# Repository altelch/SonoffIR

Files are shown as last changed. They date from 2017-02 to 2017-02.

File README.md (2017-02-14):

# SonoffIR
Sonoff IR remote controll extension for [Sonoff-Tasmota](https://github.com/arendst/Sonoff-Tasmota "Sonoff-Tasmota") and [iTead Sonoff Basic](http://sonoff.itead.cc/en/products/sonoff/sonoff-basic).
## Schematics
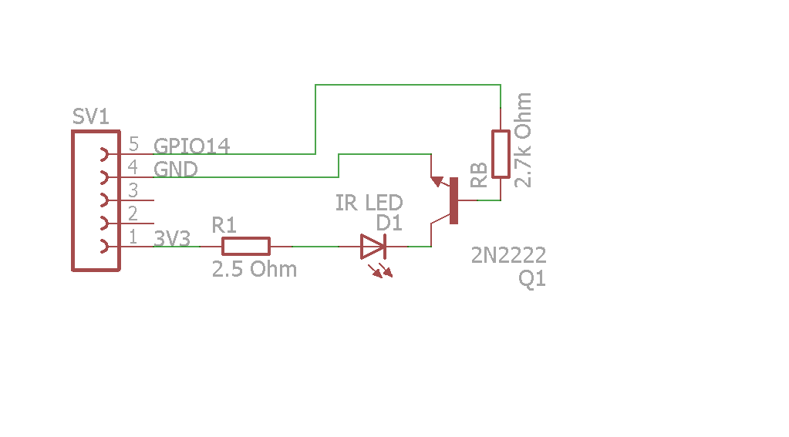
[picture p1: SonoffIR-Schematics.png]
Schematics

The resistor values depend on the used IR LED and the gain of the NPN Transistor. Rb is not really necessary an can be left out. R1 limits the current through the diod and can have Values between 2.5 Ohm and 10 Ohm. Using lower values gives you a better range but you risk the diod if the current gets to high. About 100mA are ok for sending signals. Check your datasheets!
## Board layout
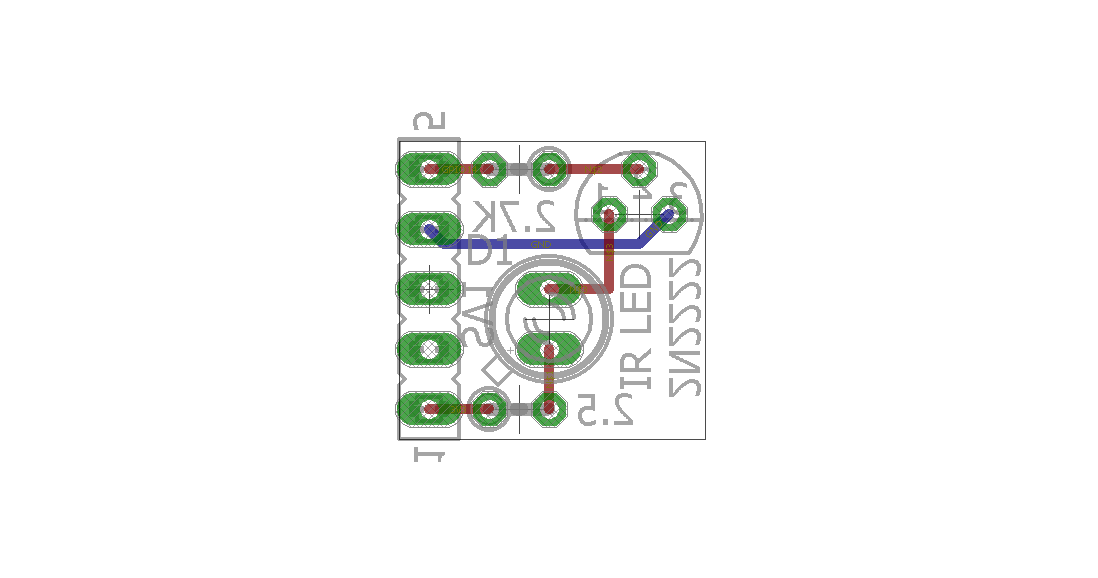
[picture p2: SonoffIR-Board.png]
Board

The diode is facing upwards, the rest downwards. The board directly fits onto the Sonoff pinheader used for programming and uses GPIO14.
## Assembly
### Parts
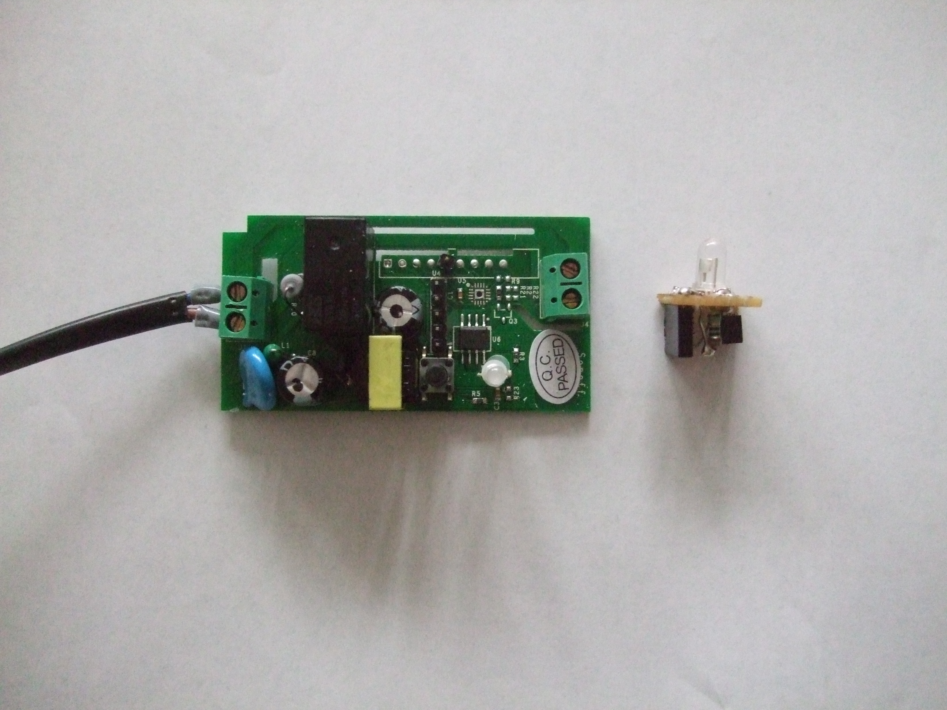
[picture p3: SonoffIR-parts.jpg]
Parts

### Board prototype
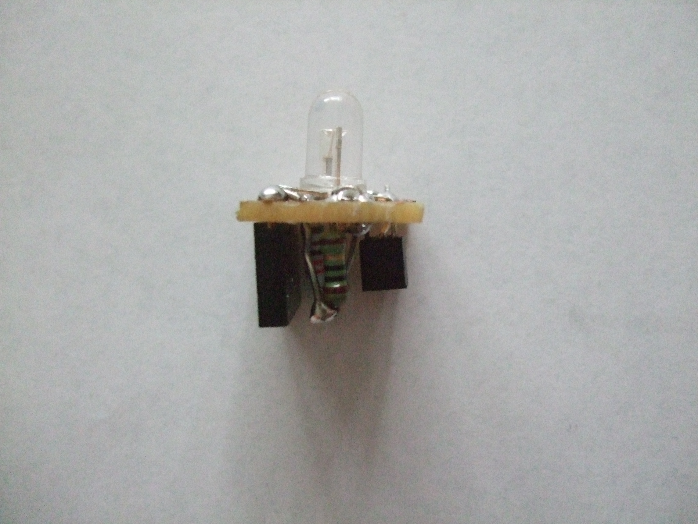
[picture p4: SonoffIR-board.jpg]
Board

### Parts fitted
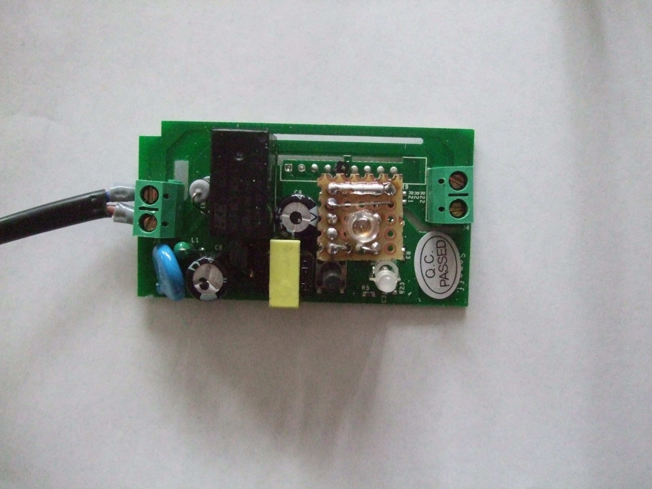
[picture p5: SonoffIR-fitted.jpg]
Fitted

### Chassis with additional hole drilled (5mm)
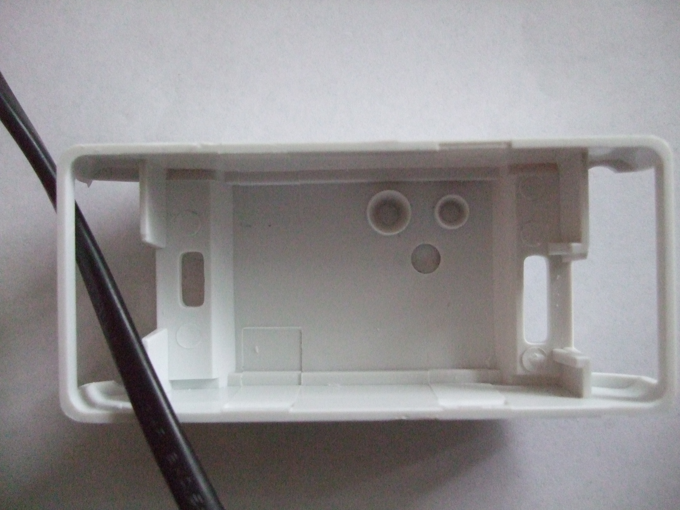
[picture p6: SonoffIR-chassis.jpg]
Chassis

### The finished SonoffIR
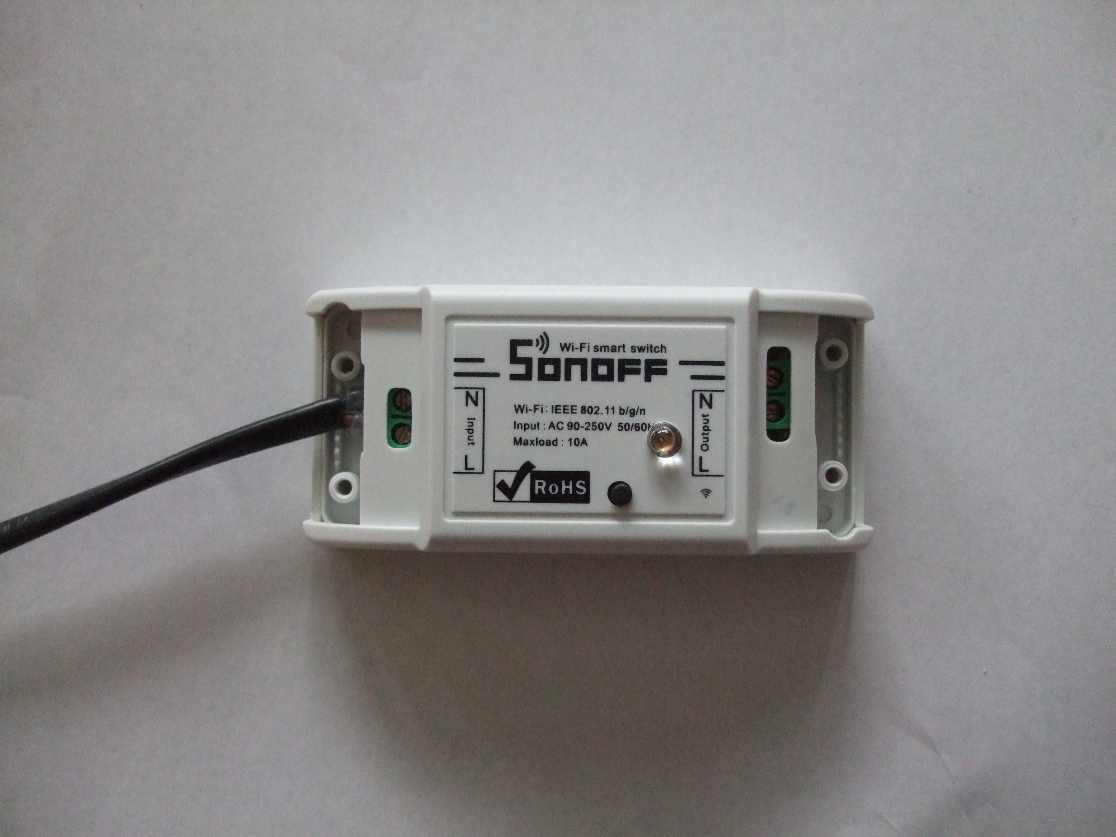
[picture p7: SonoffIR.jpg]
SonoffIR


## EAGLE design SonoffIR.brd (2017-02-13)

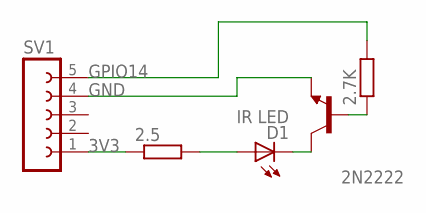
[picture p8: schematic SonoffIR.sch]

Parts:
2.5, 2.7K: R-EU_0204/2V; 0204V
2N2222: 2N3565; TO92
D1: IR LED; SFH482
SV1: FE05-1

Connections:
3V3: 2.5.1, SV1.1
GND: 2N2222.3 (E), SV1.4
GPIO14: 2.7K.2, SV1.5
unnamed: 2.5.2, D1.A
unnamed: 2.7K.1, 2N2222.2 (B)
unnamed: 2N2222.1 (C), D1.K (C)

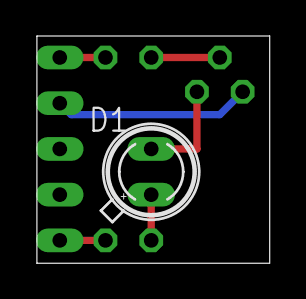
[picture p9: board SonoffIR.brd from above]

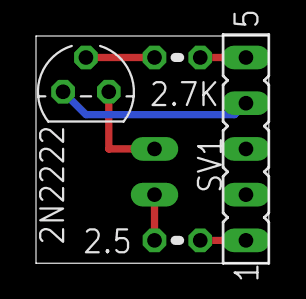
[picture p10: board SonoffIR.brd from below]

Board: 2 copper layers, 12.9 x 12.6 mm, 5 parts (4 on the bottom side), 6 nets.

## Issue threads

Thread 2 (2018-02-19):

How include this implementation to Tasmota

douglaspaulo, 2018-02-19:
Hi @altelch

How i include this irsend implementation to my Tasmota firmware?

I don´t found any code that I can insert on my Tasmota to upload for Sonoff Basic.

Can you help me implement this?

Thanks

altelch, 2018-03-28:
https://github.com/arendst/Sonoff-Tasmota/wiki/Sensor-Configuration at the Bottom to get the MQTT commands or use the webpage of your sonoff device to configure GPIO Pin 14 as IRsend.

Closed 2018-07-02.

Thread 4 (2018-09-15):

not an issue but a request

aihysp, 2018-09-15:
1. if you can please put code examples, like how to send IR code with MQTT
2. pic of the board assembled from below and above
3. what is the topic and how to config on tasomata
4. in general if you can make the docs readable for noobs it will be great :)

thanks allot!

altelch, 2021-01-30:
See Tasmota docs.

Closed 2021-01-30.

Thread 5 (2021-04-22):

Sonoff Basic R2

fmarzocca, 2021-04-22:
Hi,
in my sonoff basic R2 I don't have GPIO14. Close to the 4 holes (3v3, gnd, rx and tx) I have a pad marked IO2, without the hole. And if I drill the hole, I risk to break the upper side tracks...

altelch, 2022-11-30:
Don't have R2 to check.

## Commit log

2017-02-13 Sonoff IR remote controller hardware
    [SonoffIR.brd, SonoffIR.sch]
2017-02-13 Better Name/Value placement on Board
    [SonoffIR.brd, SonoffIR.sch]
2017-02-13 Changes in Value placement
    [SonoffIR.brd, SonoffIR.sch]
